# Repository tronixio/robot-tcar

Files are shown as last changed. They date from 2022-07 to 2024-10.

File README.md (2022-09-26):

# DRAFT - ROBOT - TCAR 4 Wheels.

## TCAR Features.

- 4 Wheels.
- 4 DC Motors.
- Power 2xCells 18650 Lithium Ion Rechargeable Batteries, with embedded charger.
- [4WD Motor Smart Car Chassis.](http://www.dagurobot.com/Robot-Chassis/HC021-P)

## TCAR All Schematics.

- [TODO - MCU Board PIC-16BIT.](https://github.com/tronixio/robot-tcar/blob/main/Kicad/mcu/extras/schematic.pdf)
- [DRAFT - Motors Board LP298.](https://github.com/tronixio/robot-tcar/blob/main/Kicad/motors/extras/schematic.pdf)

<!--
## TCAR Code.

- [PWM.](https://github.com/tronixio/robot-tbot/blob/main/Code/pwm/)

## TCAR MCU PIC 16Bit Top.

![TCAR MCU Top.](https://raw.githubusercontent.com/tronixio/robot-tcar/main/Kicad/mcu/extras/top.png)

## TCAR MCU PIC 16Bit Bottom.

![TCAR MCU Top.](https://raw.githubusercontent.com/tronixio/robot-tcar/main/Kicad/mcu/extras/top.png)
-->

## TCAR Motor Top.

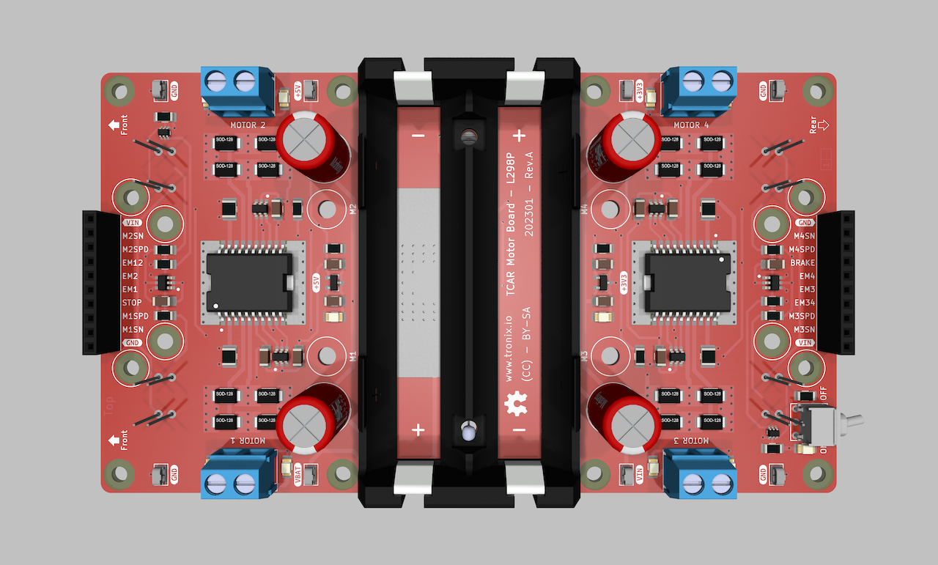
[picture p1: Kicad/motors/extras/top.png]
TCAR Motor Top.


## TCAR Motor Bottom.

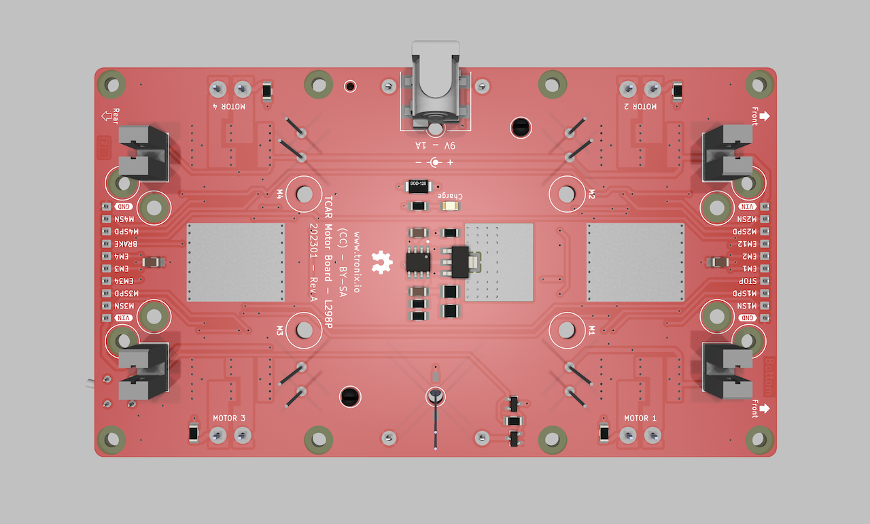
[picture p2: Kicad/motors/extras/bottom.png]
TCAR Motor Bottom.


!!! note

    - TODO : Work in progress, prototype was not good, hardware, PCB and code can be rework.
    - DRAFT : Prototype OK, last check schematic, PCB & code can be modify.

!!! example "DISCLAIMER"

    THIS CODE IS PROVIDED WITHOUT ANY WARRANTY OR GUARANTEES.
    USERS MAY USE THIS CODE FOR DEVELOPMENT AND EXAMPLE PURPOSES ONLY.
    AUTHORS ARE NOT RESPONSIBLE FOR ANY ERRORS, OMISSIONS, OR DAMAGES THAT COULD
    RESULT FROM USING THIS FIRMWARE IN WHOLE OR IN PART.

---

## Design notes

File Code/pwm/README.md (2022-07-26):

# PWM - 16-BIT Pulse-Width Modulation Module.

## Code.

- [PWM 16-BIT - RC Servo Forward & Backward.](https://github.com/tronixio/robot-tbot/blob/main/Code/pwm/pwm.s)

## Oscilloscope.

### Stop.

- MCU.RC5.PWM.6  -> Oscilloscope Probe A
- MCU.RB5.PWM.11 -> Oscilloscope Probe B

<p align="center">
PWM.6 - PWM.11
</p>

### Forward.

- MCU.RC5.PWM.6  -> Oscilloscope Probe A
- MCU.RB5.PWM.11 -> Oscilloscope Probe B

<p align="center">
PWM.6 - PWM.11
</p>

### Backward.

- MCU.RC5.PWM.6  -> Oscilloscope Probe A
- MCU.RB5.PWM.11 -> Oscilloscope Probe B

<p align="center">
PWM.6 - PWM.11
</p>

## Notes.

- TODO : Work in progress, prototype was not good, hardware, PCB and code can be rework.
- DRAFT : Prototype OK, last check schematic, PCB & code can be modify.

## DISCLAIMER.

THIS CODE IS PROVIDED WITHOUT ANY WARRANTY OR GUARANTEES.
USERS MAY USE THIS CODE FOR DEVELOPMENT AND EXAMPLE PURPOSES ONLY.
AUTHORS ARE NOT RESPONSIBLE FOR ANY ERRORS, OMISSIONS, OR DAMAGES THAT COULD
RESULT FROM USING THIS FIRMWARE IN WHOLE OR IN PART.

---

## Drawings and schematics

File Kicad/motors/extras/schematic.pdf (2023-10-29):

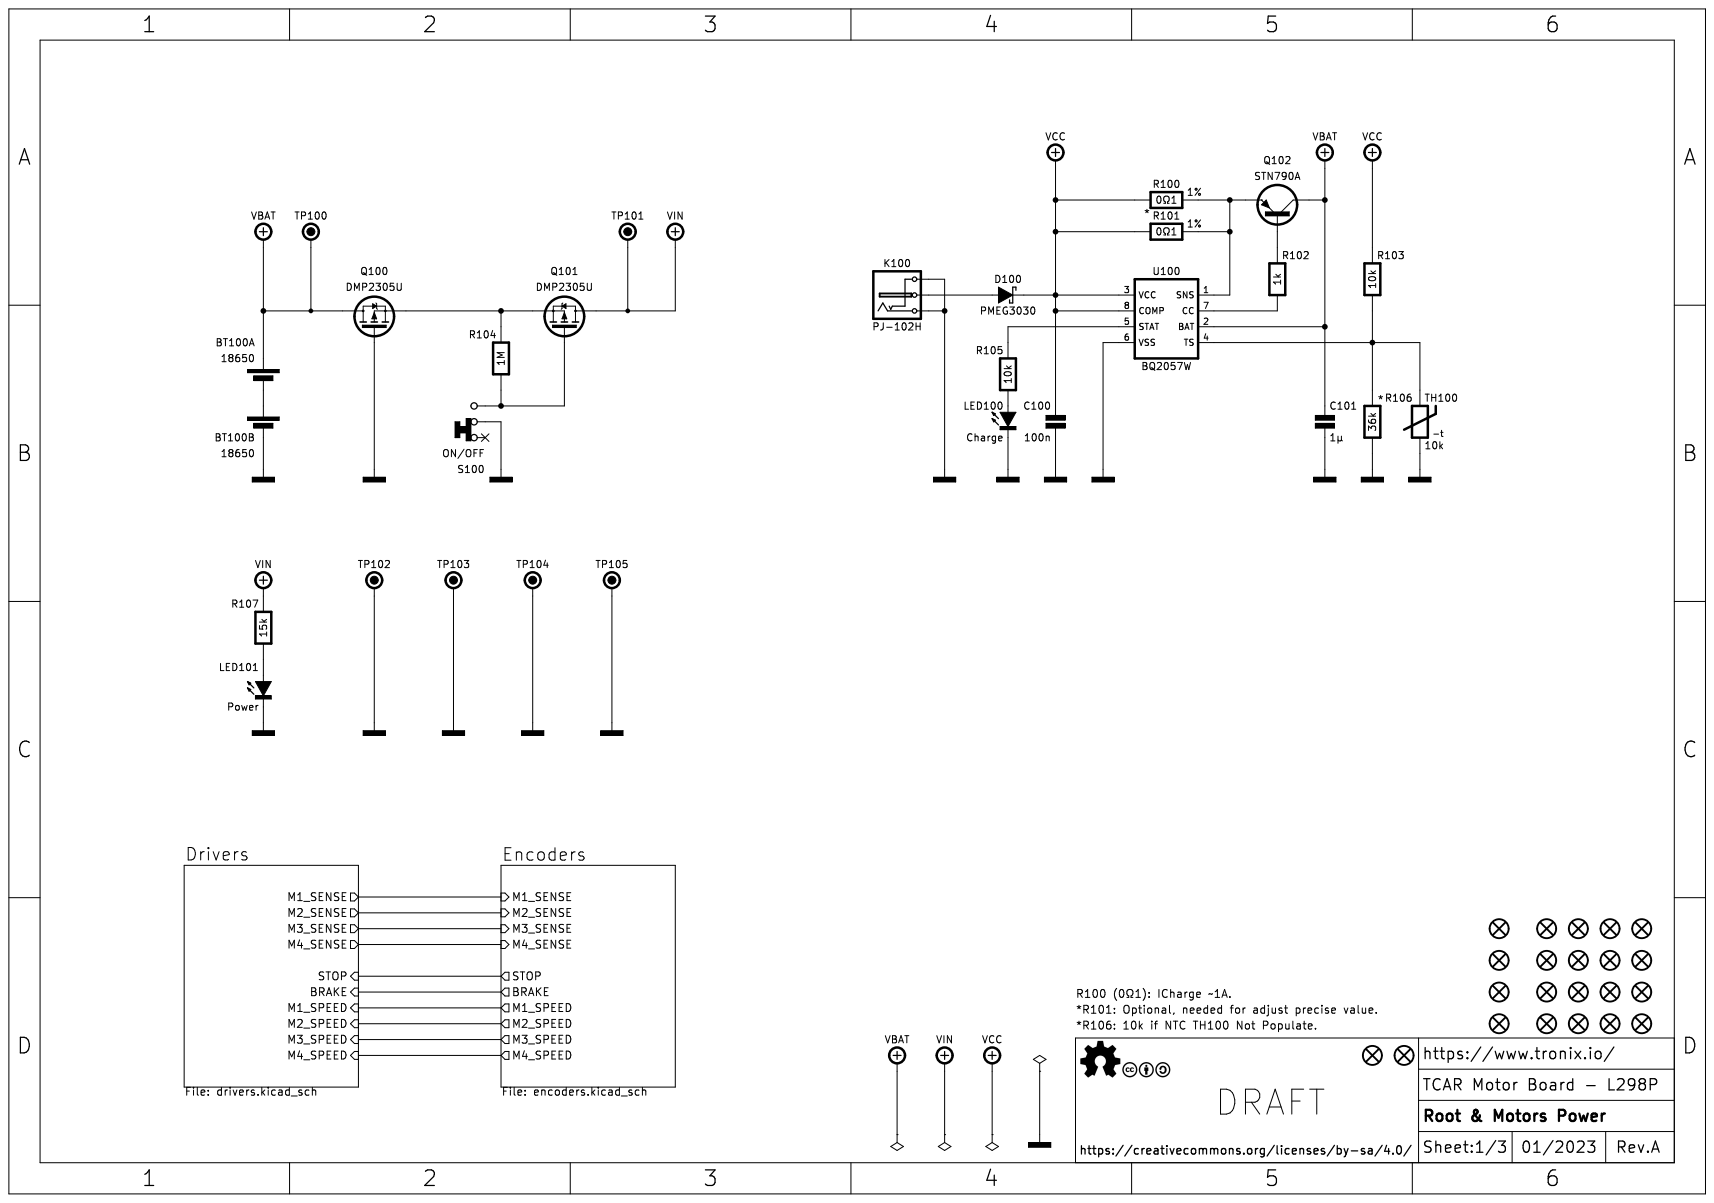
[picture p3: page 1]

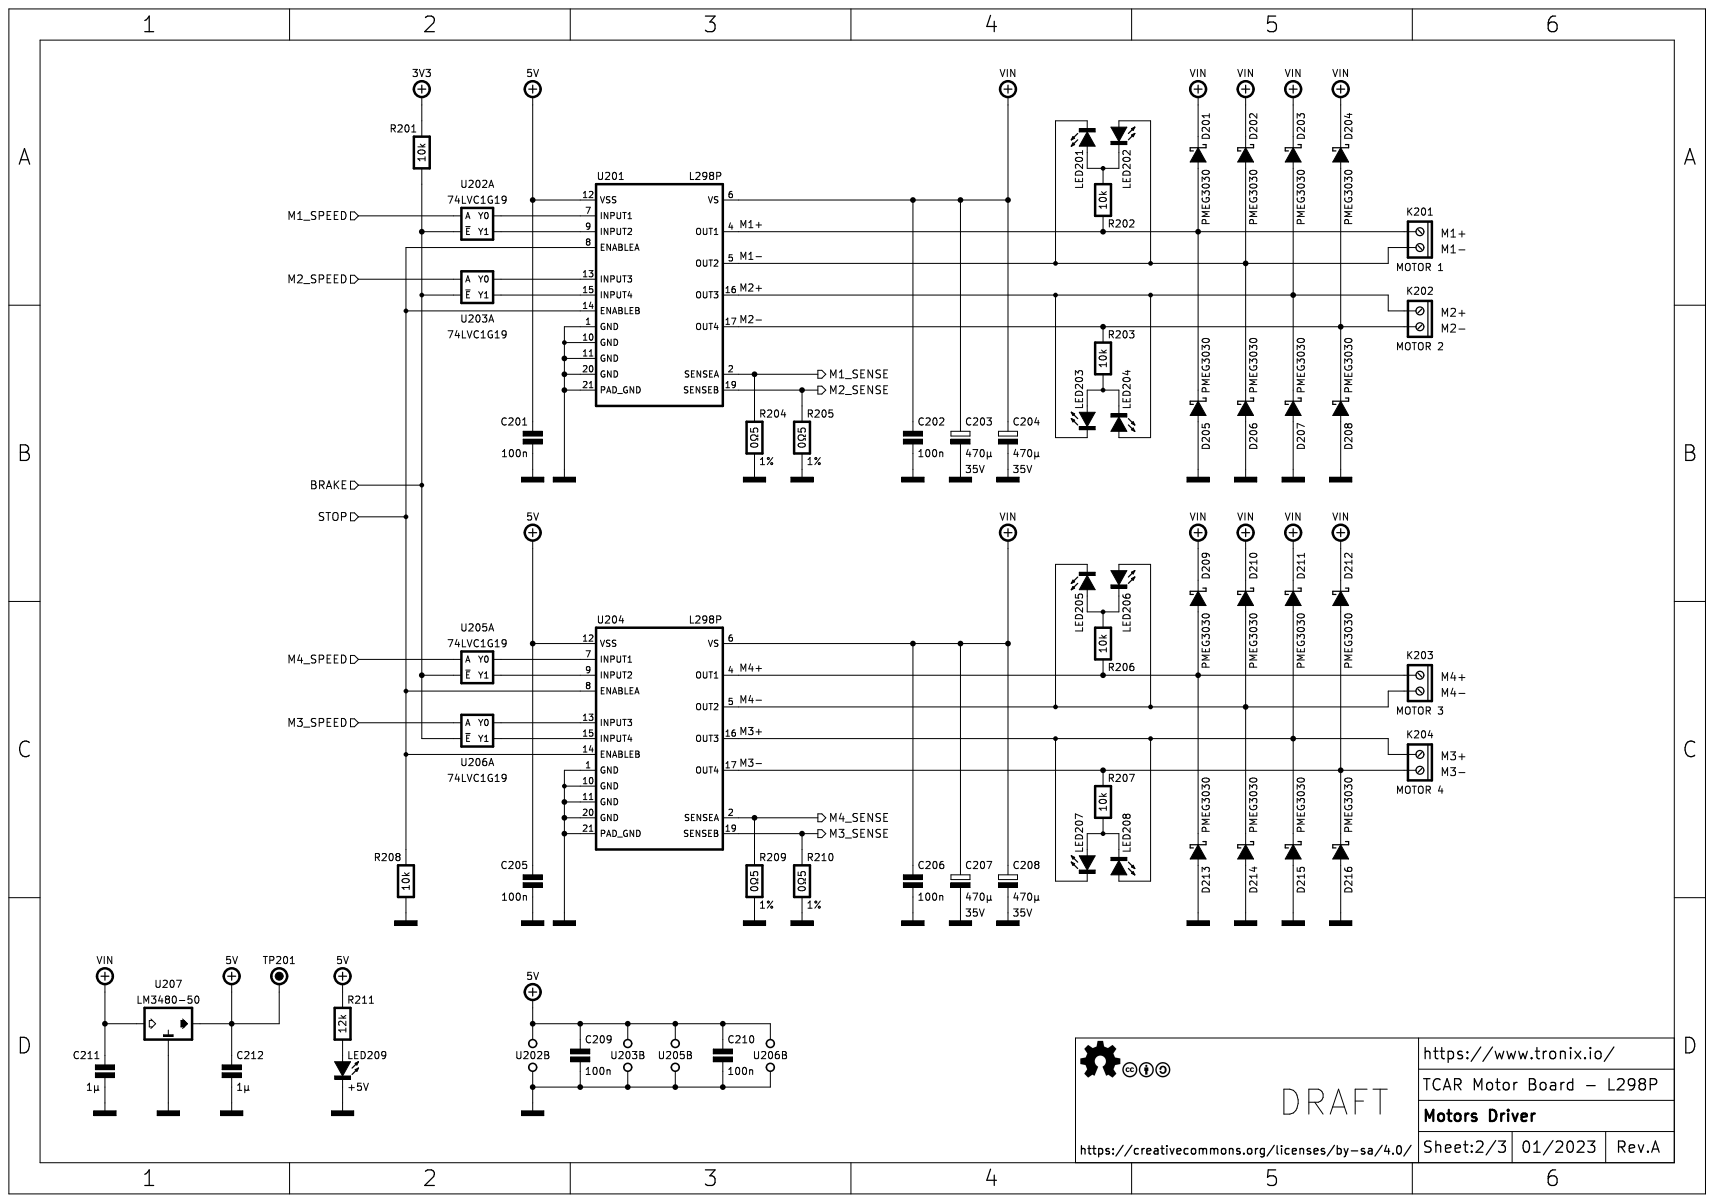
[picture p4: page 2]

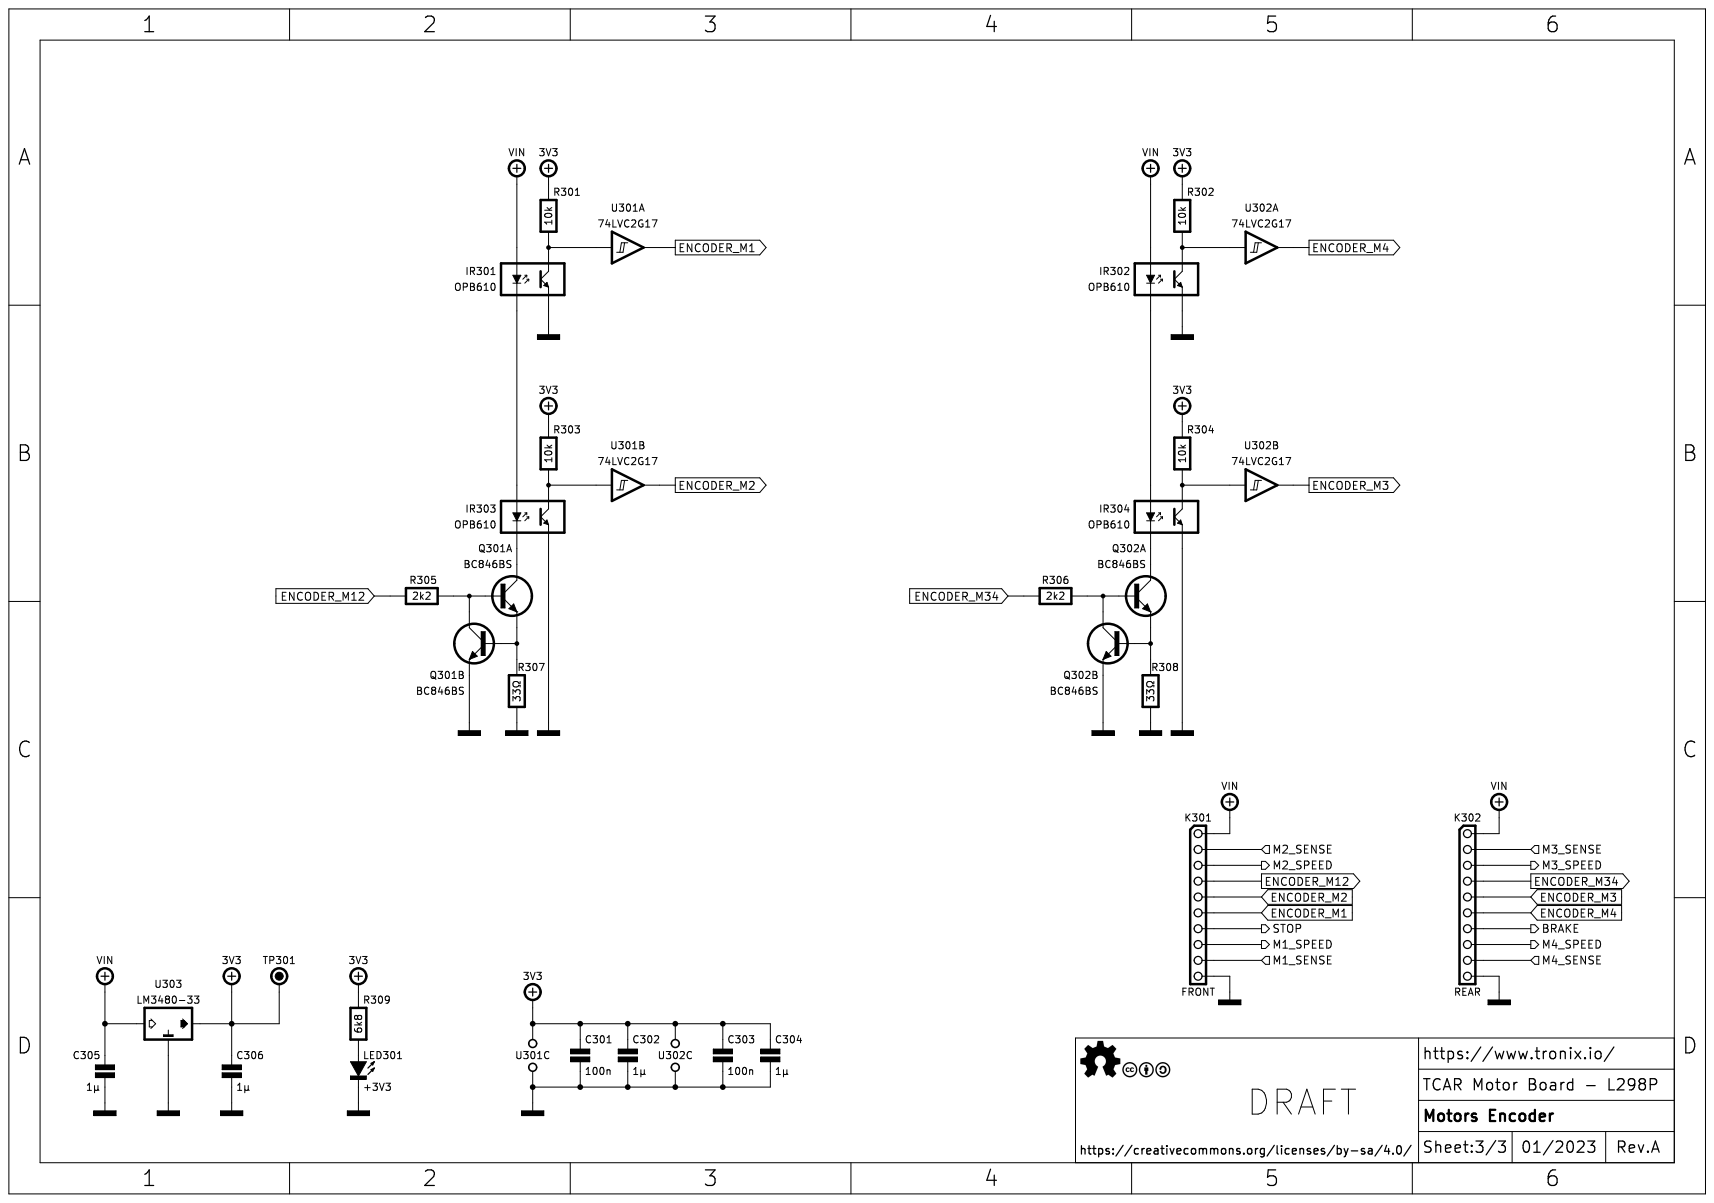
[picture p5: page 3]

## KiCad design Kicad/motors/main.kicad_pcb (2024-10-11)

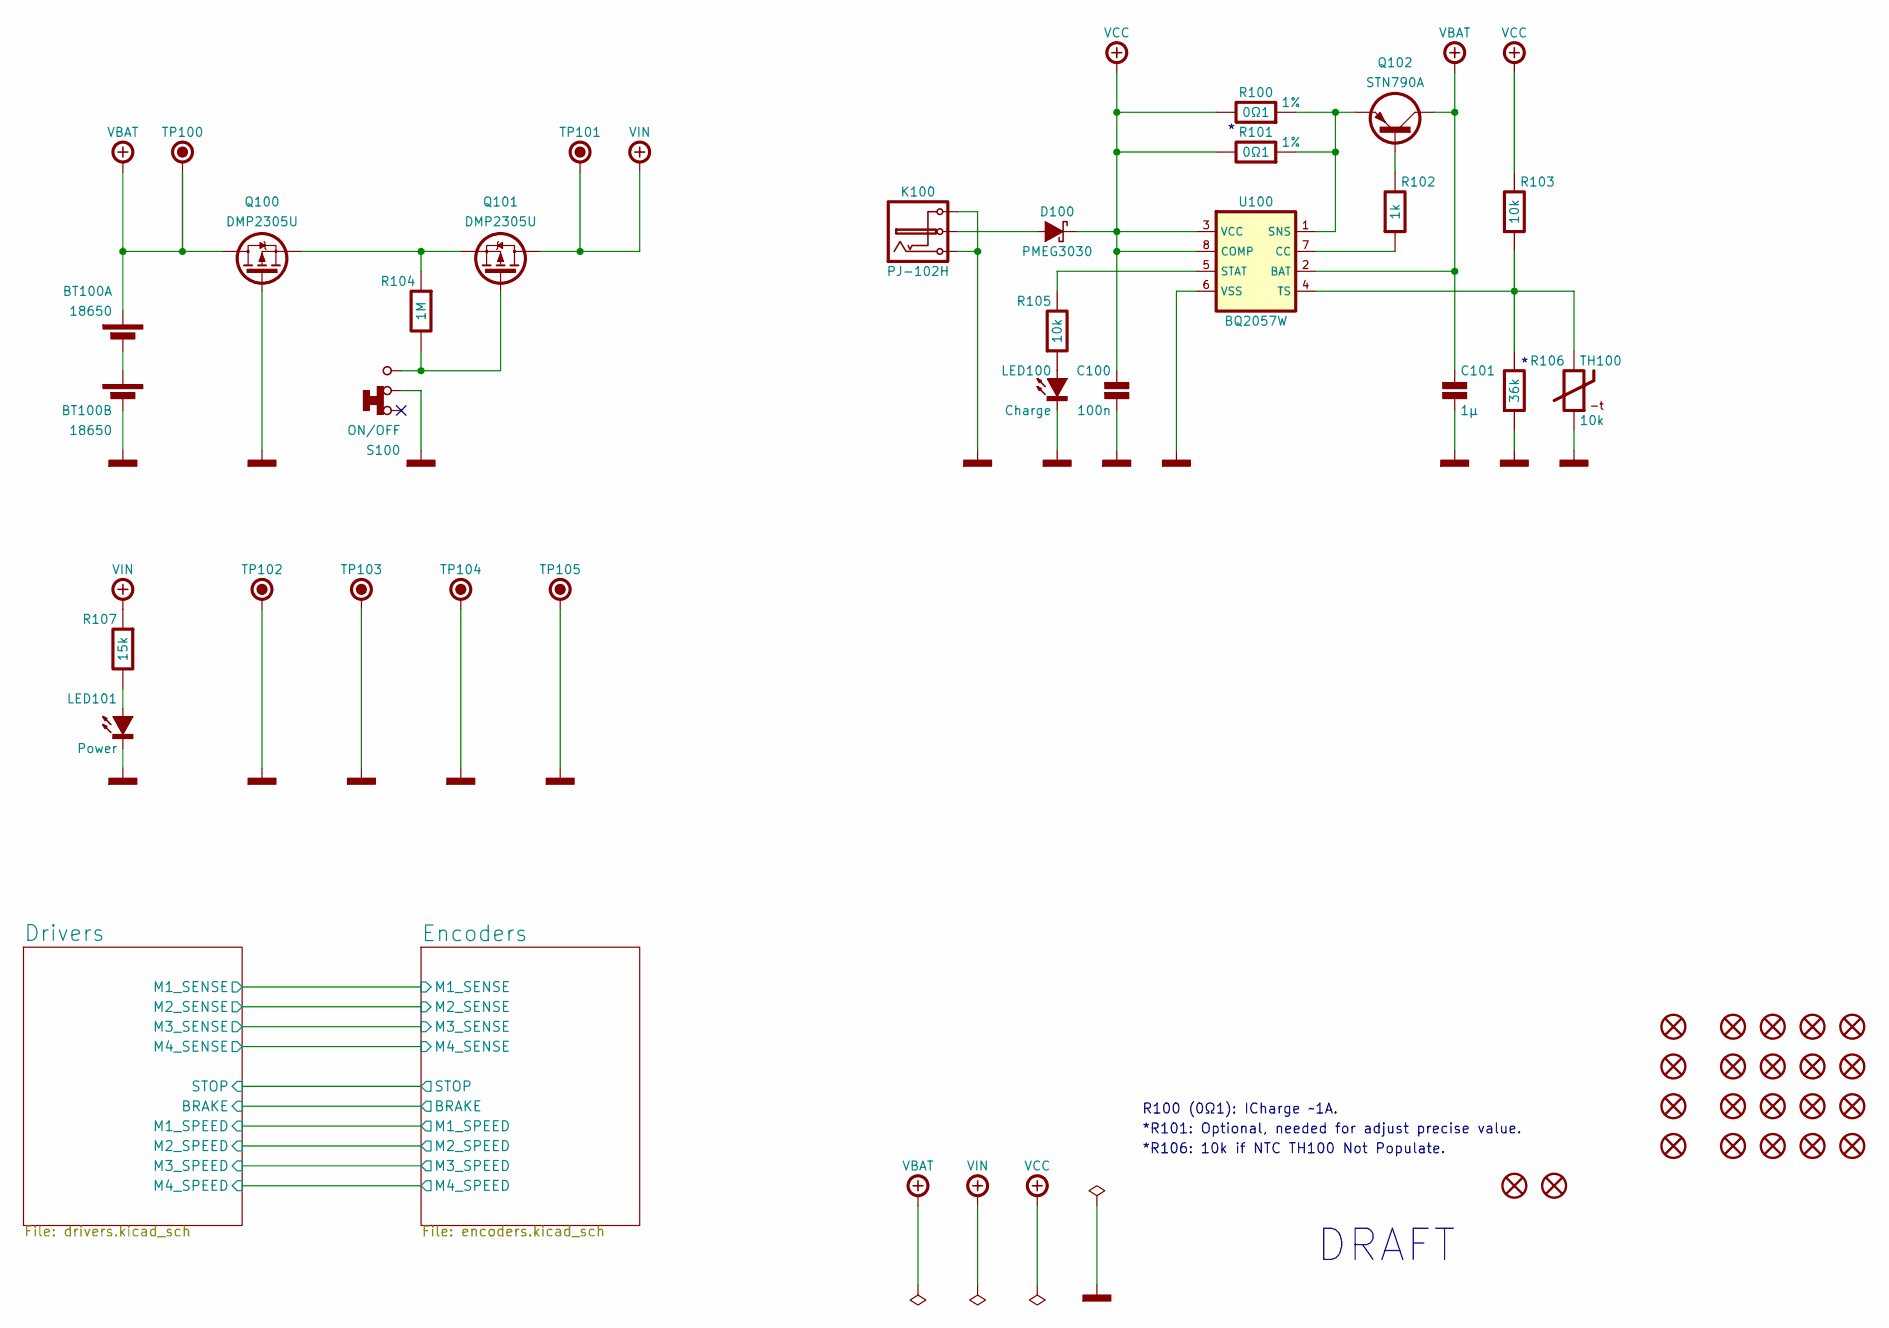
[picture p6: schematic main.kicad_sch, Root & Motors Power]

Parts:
BT100: 18650; KEYSTONE-1049; Mouser 534-1049
C100: 100n; CAPACITOR-SMD-1206; Voltage 50V; Tolerance 5%; Mouser 80-C1206C104J5R
C101: 1µ; CAPACITOR-SMD-1206; Voltage 16V; Tolerance 10%; Mouser 80-C1206C105K4R
D100: PMEG3030; SOD-128; Mouser 771-PMEG3030EP115
H101, H102, H103, H104, H105, H106, H107, H108, H109, H110, H111, H112, H113, H114, H115, H116: MOUNTING-HOLE-3MM-MASK
H117, H118, H119, H120: MOUNTING-HOLE-3.5MM
K100: PJ-102H; CUI-PJ-002AH-SMT-TR; Mouser 490-PJ-002AH-SMT-TR
LED100: Charge; LED-SMD-1206; Mouser 604-APT3216LSECKJ3RV
LED101: Power; LED-SMD-1206; Mouser 604-APT3216LSECKJ3RV
Q100, Q101: DMP2305U; SOT-23-3; Mouser 621-DMP2305U-7
Q102: STN790A; SOT-223-3; Mouser 511-STN790A
R100, R101: 0Ω1; RESISTOR-SMD-1210; Tolerance 1%; Mouser 660-SR732ETTER100F
R102: 1k; RESISTOR-SMD-1206; Tolerance 5%; Mouser 660-RK73B2BTTDD102J
R103, R105: 10k; RESISTOR-SMD-1206; Tolerance 5%; Mouser 660-RK73B2BTTDD103J
R104: 1M; RESISTOR-SMD-1206; Tolerance 5%; Mouser 660-RK73B2BTTDD105J
R106: 36k; RESISTOR-SMD-1206; Tolerance 5%; Mouser 660-RK73B2BTTDD363J
R107: 15k; RESISTOR-SMD-1206; Tolerance 5%; Mouser 660-RK73B2BTTDD153J
S100: ON/OFF; E-SWITCH-200USPXT1A1M6RE; Mouser 612-200USP1T1A1M6RE
TH100: 10k; THERMISTOR-SMD; Mouser 594-NTCLE213E3103FL
TP100, TP101, TP102, TP103, TP104, TP105: HARWIN-S1751; Mouser 855-S1751-46
U100: BQ2057W; SOIC-08; Mouser 595-BQ2057WSN
X101, X102: OSHW-5MM

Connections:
+VBAT: BT100.2 (+), C101.1, Q100.3 (D), Q102.2 (C), TP100.1, U100.2 (BAT)
+VCC: C100.1, D100.1 (C), R100.1, R101.1, R103.1, U100.3 (VCC), U100.8 (COMP)
+VIN: Q101.3 (D), R107.2, TP101.1; also elsewhere on the board
GND: BT100.3 (-), C100.2, C101.2, K100.2, K100.3, LED100.1 (C), LED101.1 (C), Q100.1 (G), R106.2, S100.2, TH100.2, TP102.1, TP103.1, TP104.1, TP105.1, U100.6 (VSS); also elsewhere on the board
unnamed: BT100.1 (-), BT100.4 (+)
unnamed: D100.2 (A), K100.1
unnamed: LED100.2 (A), R105.2
unnamed: LED101.2 (A), R107.1
unnamed: Q100.2 (S), Q101.2 (S), R104.2
unnamed: Q101.1 (G), R104.1, S100.3
unnamed: Q102.1 (B), R102.1
unnamed: Q102.3 (E), R100.2, R101.2, U100.1 (SNS)
unnamed: R102.2, U100.7 (CC)
unnamed: R105.1, U100.5 (STAT)
unnamed: R103.2, R106.1, TH100.1, U100.4 (TS)

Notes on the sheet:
DRAFT
*R101: Optional, needed for adjust precise value.
*R106: 10k if NTC TH100 Not Populate.
R100 (0Ω1): ICharge ~1A.

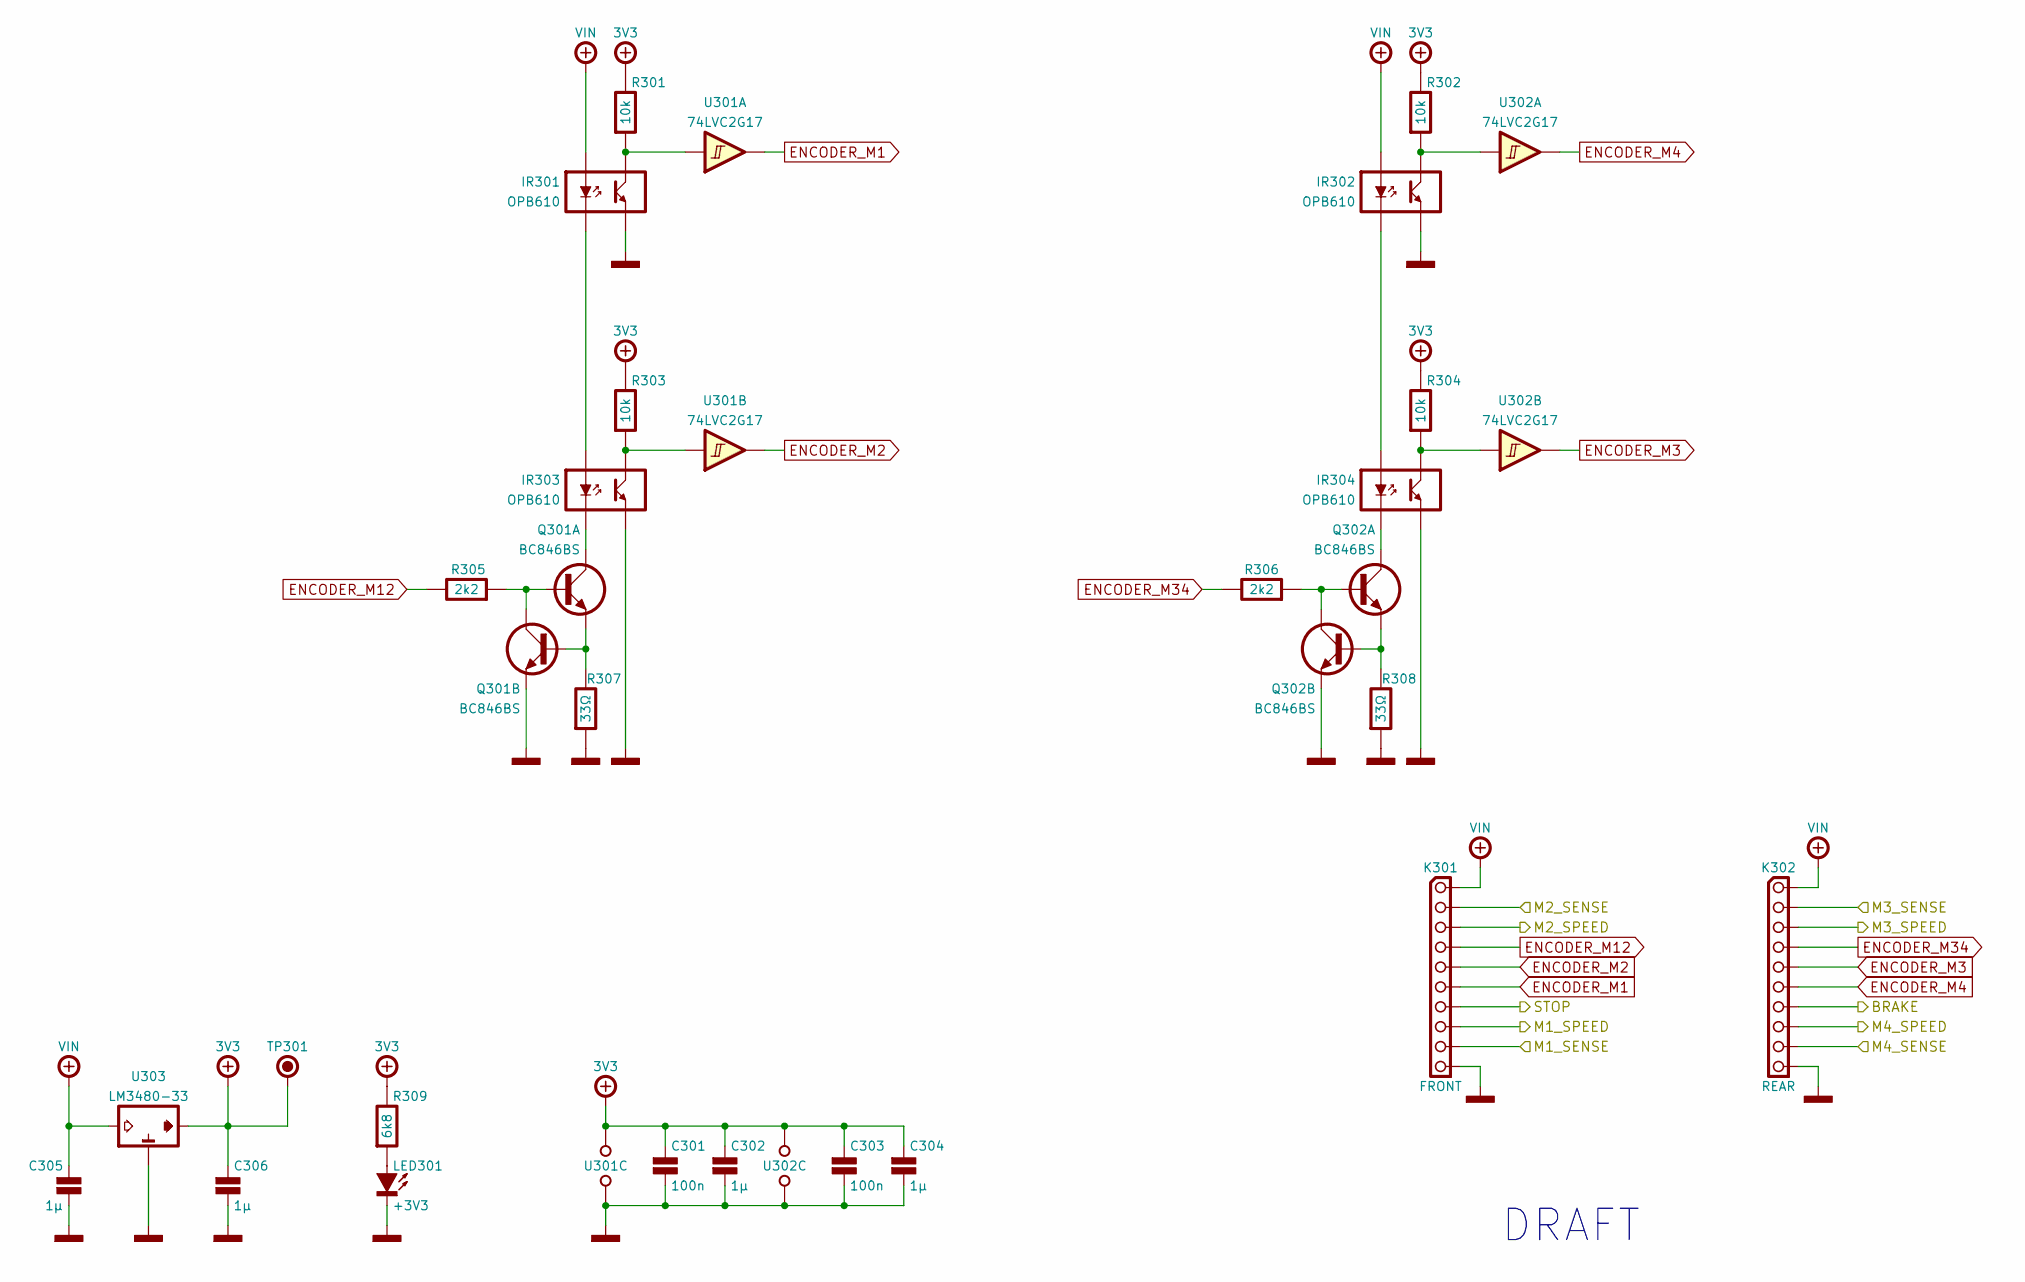
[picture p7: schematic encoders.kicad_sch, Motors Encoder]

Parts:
C301, C303: 100n; CAPACITOR-SMD-1206; Voltage 50V; Tolerance 5%; Mouser 80-C1206C104J5R
C302, C304, C305, C306: 1µ; CAPACITOR-SMD-1206; Voltage 16V; Tolerance 10%; Mouser 80-C1206C105K4R
IR301, IR302, IR303, IR304: OPB610; OPB-610; Mouser 828-OPB610
K301: FRONT; HARWIN-M20-782104x; Mouser 855-M20-782104
K302: REAR; HARWIN-M20-782104x; Mouser 855-M20-782104
LED301: +3V3; LED-SMD-1206; Mouser 604-APT3216LSECKJ3RV
Q301, Q302: BC846BS; SC-70-6; Mouser 771-BC846BS115
R301, R302, R303, R304: 10k; RESISTOR-SMD-1206; Tolerance 5%; Mouser 660-RK73B2BTTDD103J
R305, R306: 2k2; RESISTOR-SMD-1206; Tolerance 5%; Mouser 660-RK73B2BTTDD222J
R307, R308: 33Ω; RESISTOR-SMD-1206; Tolerance 5%; Mouser 660-RK73B2BTTDD330J
R309: 6k8; RESISTOR-SMD-1206; Tolerance 5%; Mouser 660-RK73B2BTTD682J
TP301: HARWIN-S1751; Mouser 855-S1751-46
U301, U302: 74LVC2G17; SOT-23-6; Mouser 595-SN74LVC2G17D
U303: LM3480-33; SOT-23-3; Mouser 926-LM3480IM33.3NOPB

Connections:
+3V3: C301.1, C302.1, C303.1, C304.1, C306.1, R301.1, R302.1, R303.1, R304.1, R309.1, TP301.1, U301.5 (VCC), U302.5 (VCC), U303.1 (VOUT); also elsewhere on the board
+VIN: C305.1, IR301.1 (ANODE), IR302.1 (ANODE), K301.1, K302.1, U303.2 (VIN); also elsewhere on the board
/Drivers/BRAKE: K302.7; also elsewhere on the board
/Drivers/M1_SENSE: K301.9; also elsewhere on the board
/Drivers/M1_SPEED: K301.8; also elsewhere on the board
/Drivers/M2_SENSE: K301.2; also elsewhere on the board
/Drivers/M2_SPEED: K301.3; also elsewhere on the board
/Drivers/M3_SENSE: K302.2; also elsewhere on the board
/Drivers/M3_SPEED: K302.3; also elsewhere on the board
/Drivers/M4_SENSE: K302.9; also elsewhere on the board
/Drivers/M4_SPEED: K302.8; also elsewhere on the board
/Drivers/STOP: K301.7; also elsewhere on the board
ENCODER_M1: K301.6, U301.6 (1Y)
ENCODER_M2: K301.5, U301.4 (2Y)
ENCODER_M3: K302.5, U302.4 (2Y)
ENCODER_M4: K302.6, U302.6 (1Y)
ENCODER_M12: K301.4, R305.1
ENCODER_M34: K302.4, R306.1
GND: C301.2, C302.2, C303.2, C304.2, C305.2, C306.2, IR301.4 (EMITTER), IR302.4 (EMITTER), IR303.4 (EMITTER), IR304.4 (EMITTER), K301.10, K302.10, LED301.1 (C), Q301.4 (E), Q302.4 (E), R307.2, R308.2, U301.2 (GND), U302.2 (GND), U303.3 (GND); also elsewhere on the board
unnamed: IR301.2 (CATHODE), IR303.1 (ANODE)
unnamed: IR301.3 (COLLECTOR), R301.2, U301.1 (1A)
unnamed: IR302.2 (CATHODE), IR304.1 (ANODE)
unnamed: IR302.3 (COLLECTOR), R302.2, U302.1 (1A)
unnamed: IR303.2 (CATHODE), Q301.6 (C)
unnamed: IR303.3 (COLLECTOR), R303.2, U301.3 (2A)
unnamed: IR304.2 (CATHODE), Q302.6 (C)
unnamed: IR304.3 (COLLECTOR), R304.2, U302.3 (2A)
unnamed: LED301.2 (A), R309.2
unnamed: Q301.2 (B), Q301.3 (C), R305.2
unnamed: Q301.1 (E), Q301.5 (B), R307.1
unnamed: Q302.2 (B), Q302.3 (C), R306.2
unnamed: Q302.1 (E), Q302.5 (B), R308.1

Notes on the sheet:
DRAFT

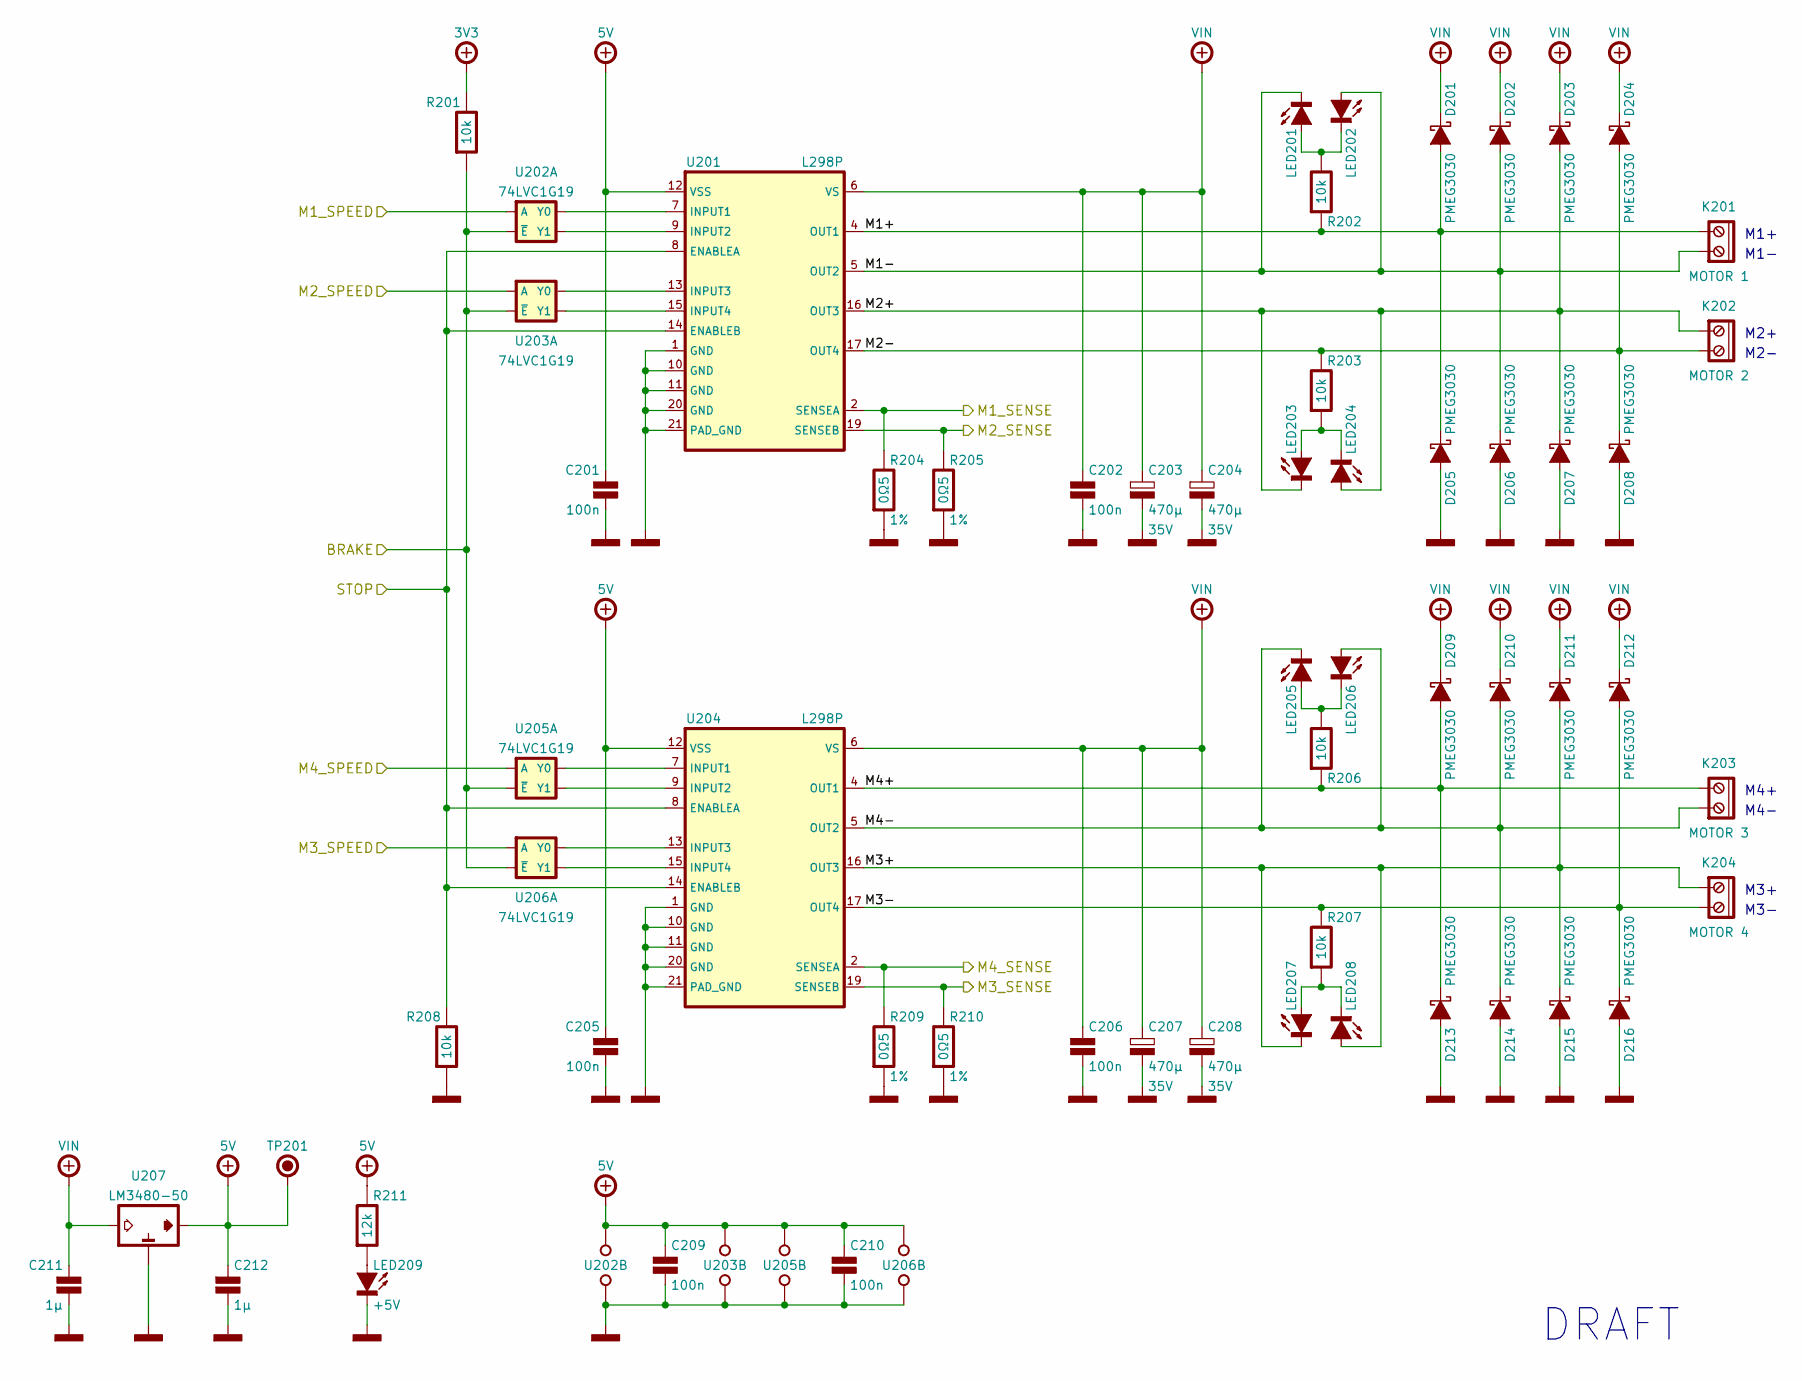
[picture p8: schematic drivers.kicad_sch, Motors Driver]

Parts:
C201, C202, C205, C206, C209, C210: 100n; CAPACITOR-SMD-1206; Voltage 50V; Tolerance 5%; Mouser 80-C1206C104J5R
C203, C204, C207, C208: 470µ; CAPACITOR-ELECTROLYTIC-RADIAL-100-160-050-WURTH; Tolerance 20%; Voltage 35V; Mouser 710-860010575013
C211, C212: 1µ; CAPACITOR-SMD-1206; Voltage 16V; Tolerance 10%; Mouser 80-C1206C105K4R
D201, D202, D203, D204, D205, D206, D207, D208, D209, D210, D211, D212, D213, D214, D215, D216: PMEG3030; SOD-128; Mouser 771-PMEG3030EP115
K201: MOTOR 1; CUI-TB006-508-02BE; Mouser 490-TB006-508-02BE
K202: MOTOR 2; CUI-TB006-508-02BE; Mouser 490-TB006-508-02BE
K203: MOTOR 3; CUI-TB006-508-02BE; Mouser 490-TB006-508-02BE
K204: MOTOR 4; CUI-TB006-508-02BE; Mouser 490-TB006-508-02BE
LED201, LED202, LED203, LED204, LED205, LED206, LED207, LED208: RED; LED-SMD-1206; Mouser 604-APT3216LSECKJ3RV
LED209: +5V; LED-SMD-1206; Mouser 604-APT3216LSECKJ3RV
R201, R202, R203, R206, R207, R208: 10k; RESISTOR-SMD-1206; Tolerance 5%; Mouser 660-RK73B2BTTDD103J
R204, R205, R209, R210: 0Ω5; RESISTOR-SMD-1210; Tolerance 1%; Mouser 660-SR732ETTDR499F
R211: 12k; RESISTOR-SMD-1206; Tolerance 5%; Mouser 660-RK73B2BTTD123J
TP201: HARWIN-S1751; Mouser 855-S1751-46
U201, U204: L298P; SOPOWER-20; Mouser 511-L298P-TR
U202, U203, U205, U206: 74LVC1G19; SOT-23-6; Mouser 595-SN74LVC1G19D
U207: LM3480-50; SOT-23-3; Mouser 926-LM3480IM35.0NOPB

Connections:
+3V3: R201.1; also elsewhere on the board
+5V: C201.1, C205.1, C209.1, C210.1, C212.1, R211.1, TP201.1, U201.12 (VSS), U202.5 (VCC), U203.5 (VCC), U204.12 (VSS), U205.5 (VCC), U206.5 (VCC), U207.1 (VOUT)
+VIN: C202.1, C203.1, C204.1, C206.1, C207.1, C208.1, C211.1, D201.1 (C), D202.1 (C), D203.1 (C), D204.1 (C), D209.1 (C), D210.1 (C), D211.1 (C), D212.1 (C), U201.6 (VS), U204.6 (VS), U207.2 (VIN); also elsewhere on the board
/Drivers/BRAKE: R201.2, U202.3 (~E), U203.3 (~E), U205.3 (~E), U206.3 (~E); also elsewhere on the board
/Drivers/M1+: D201.2 (A), D205.1 (C), K201.2, R202.2, U201.4 (OUT1)
/Drivers/M1-: D202.2 (A), D206.1 (C), K201.1, LED201.1 (C), LED202.2 (A), U201.5 (OUT2)
/Drivers/M1_SENSE: R204.1, U201.2 (SENSEA); also elsewhere on the board
/Drivers/M1_SPEED: U202.1 (A); also elsewhere on the board
/Drivers/M2+: D203.2 (A), D207.1 (C), K202.1, LED203.1 (C), LED204.2 (A), U201.16 (OUT3)
/Drivers/M2-: D204.2 (A), D208.1 (C), K202.2, R203.1, U201.17 (OUT4)
/Drivers/M2_SENSE: R205.1, U201.19 (SENSEB); also elsewhere on the board
/Drivers/M2_SPEED: U203.1 (A); also elsewhere on the board
/Drivers/M3+: D211.2 (A), D215.1 (C), K204.1, LED207.1 (C), LED208.2 (A), U204.16 (OUT3)
/Drivers/M3-: D212.2 (A), D216.1 (C), K204.2, R207.1, U204.17 (OUT4)
/Drivers/M3_SENSE: R210.1, U204.19 (SENSEB); also elsewhere on the board
/Drivers/M3_SPEED: U206.1 (A); also elsewhere on the board
/Drivers/M4+: D209.2 (A), D213.1 (C), K203.2, R206.2, U204.4 (OUT1)
/Drivers/M4-: D210.2 (A), D214.1 (C), K203.1, LED205.1 (C), LED206.2 (A), U204.5 (OUT2)
/Drivers/M4_SENSE: R209.1, U204.2 (SENSEA); also elsewhere on the board
/Drivers/M4_SPEED: U205.1 (A); also elsewhere on the board
/Drivers/STOP: R208.1, U201.8 (ENABLEA), U201.14 (ENABLEB), U204.8 (ENABLEA), U204.14 (ENABLEB); also elsewhere on the board
GND: C201.2, C202.2, C203.2, C204.2, C205.2, C206.2, C207.2, C208.2, C209.2, C210.2, C211.2, C212.2, D205.2 (A), D206.2 (A), D207.2 (A), D208.2 (A), D213.2 (A), D214.2 (A), D215.2 (A), D216.2 (A), LED209.1 (C), R204.2, R205.2, R208.2, R209.2, R210.2, U201.1 (GND), U201.10 (GND), U201.11 (GND), U201.20 (GND), U201.21 (PAD_GND), U202.2 (GND), U203.2 (GND), U204.1 (GND), U204.10 (GND), U204.11 (GND), U204.20 (GND), U204.21 (PAD_GND), U205.2 (GND), U206.2 (GND), U207.3 (GND); also elsewhere on the board
unnamed: LED201.2 (A), LED202.1 (C), R202.1
unnamed: LED203.2 (A), LED204.1 (C), R203.2
unnamed: LED205.2 (A), LED206.1 (C), R206.1
unnamed: LED207.2 (A), LED208.1 (C), R207.2
unnamed: LED209.2 (A), R211.2
unnamed: U201.7 (INPUT1), U202.6 (Y0)
unnamed: U201.9 (INPUT2), U202.4 (Y1)
unnamed: U201.13 (INPUT3), U203.6 (Y0)
unnamed: U201.15 (INPUT4), U203.4 (Y1)
unnamed: U204.7 (INPUT1), U205.6 (Y0)
unnamed: U204.9 (INPUT2), U205.4 (Y1)
unnamed: U204.13 (INPUT3), U206.6 (Y0)
unnamed: U204.15 (INPUT4), U206.4 (Y1)

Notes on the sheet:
M3-
M1+
M2+
M4-
M2-
DRAFT
M3+
M4+
M1-

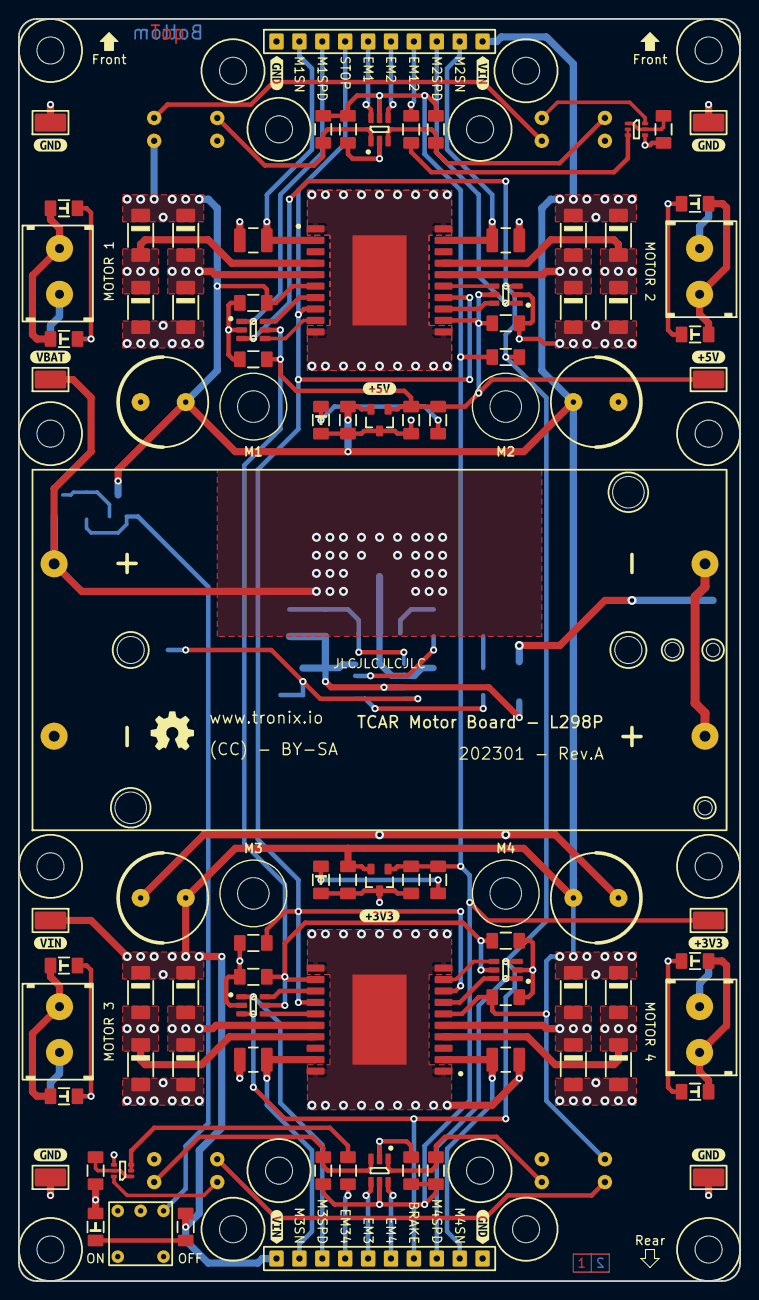
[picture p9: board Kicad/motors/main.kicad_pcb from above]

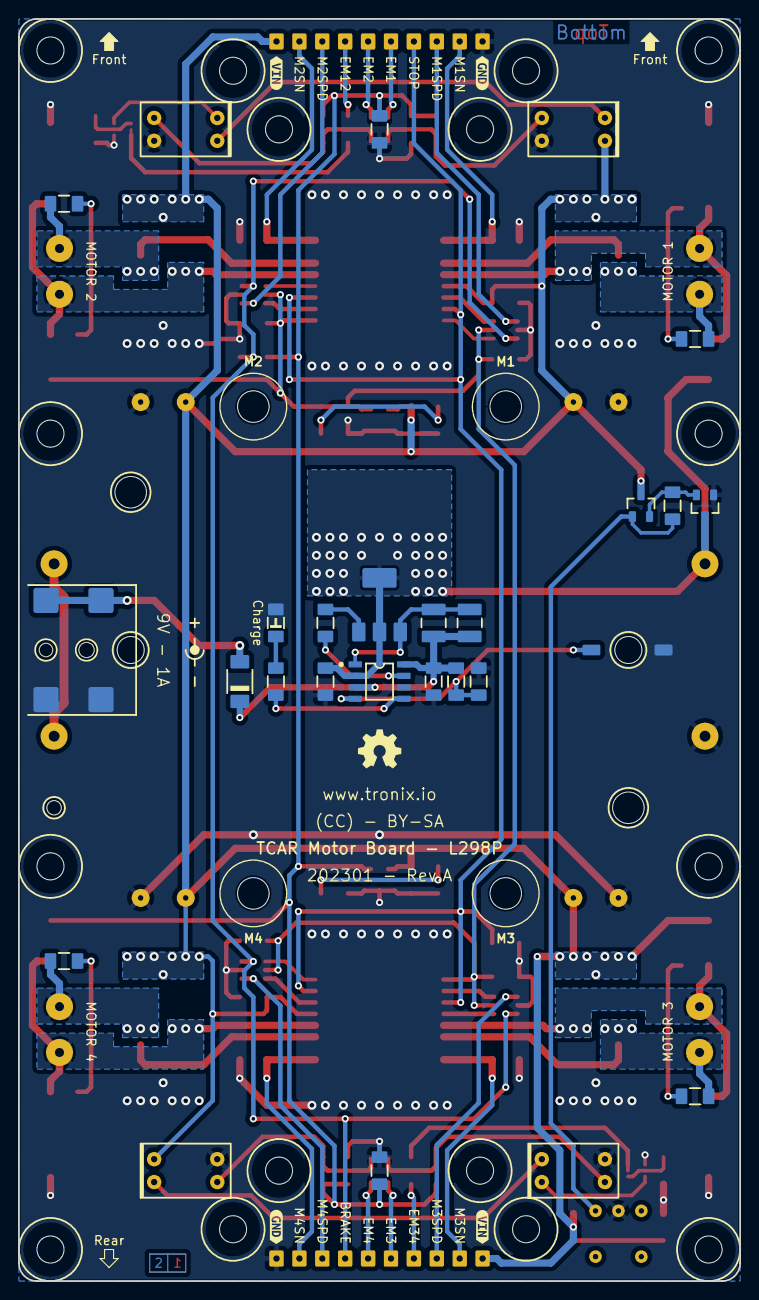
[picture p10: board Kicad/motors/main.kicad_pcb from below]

Board: 2 copper layers, 80.0 x 140.0 mm, 155 parts (32 on the bottom side), 67 nets.

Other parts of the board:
kibuzzard-64482FBD: G***; kibuzzard-64482FBD
kibuzzard-64482FE5: G***; kibuzzard-64482FE5
kibuzzard-628974BE, kibuzzard-628974BE#2: G***; kibuzzard-628974BE
kibuzzard-628977DB: G***; kibuzzard-628977DB
kibuzzard-628977F0: G***; kibuzzard-628977F0
kibuzzard-6289753B, kibuzzard-6289753B#2: G***; kibuzzard-6289753B
kibuzzard-6289769F, kibuzzard-6289769F#2: G***; kibuzzard-6289769F
kibuzzard-6289784D: G***; kibuzzard-6289784D
kibuzzard-6289786A: G***; kibuzzard-6289786A
kibuzzard-62897416, kibuzzard-62897416#2: G***; kibuzzard-62897416
kibuzzard-62897505, kibuzzard-62897505#2: G***; kibuzzard-62897505
kibuzzard-62897802: G***; kibuzzard-62897802
kibuzzard-62897881: G***; kibuzzard-62897881

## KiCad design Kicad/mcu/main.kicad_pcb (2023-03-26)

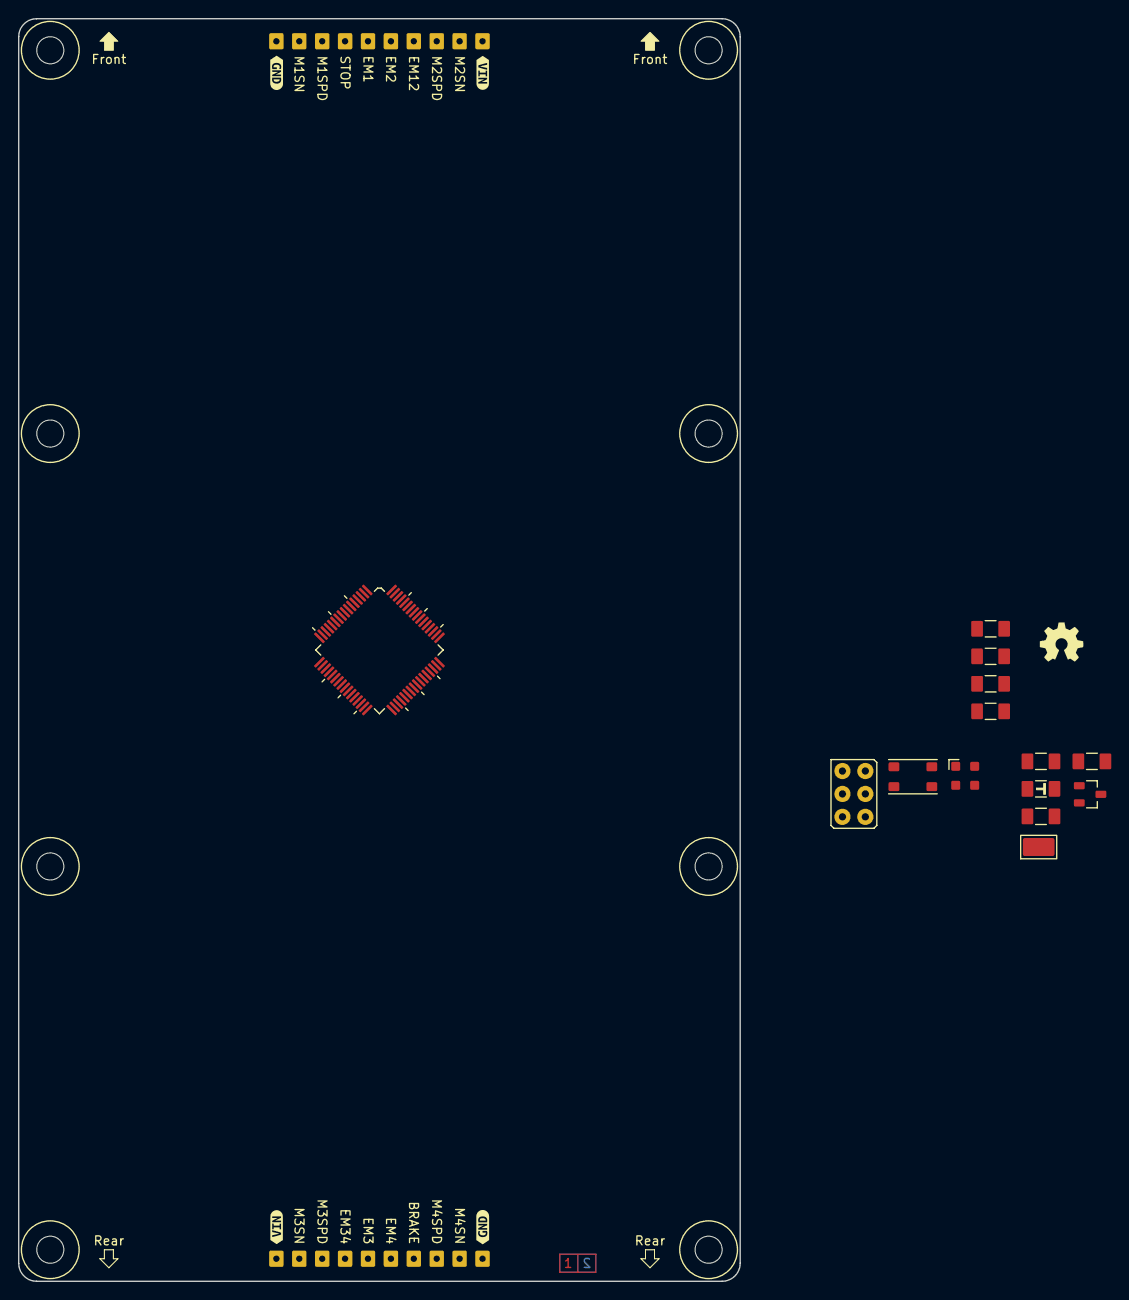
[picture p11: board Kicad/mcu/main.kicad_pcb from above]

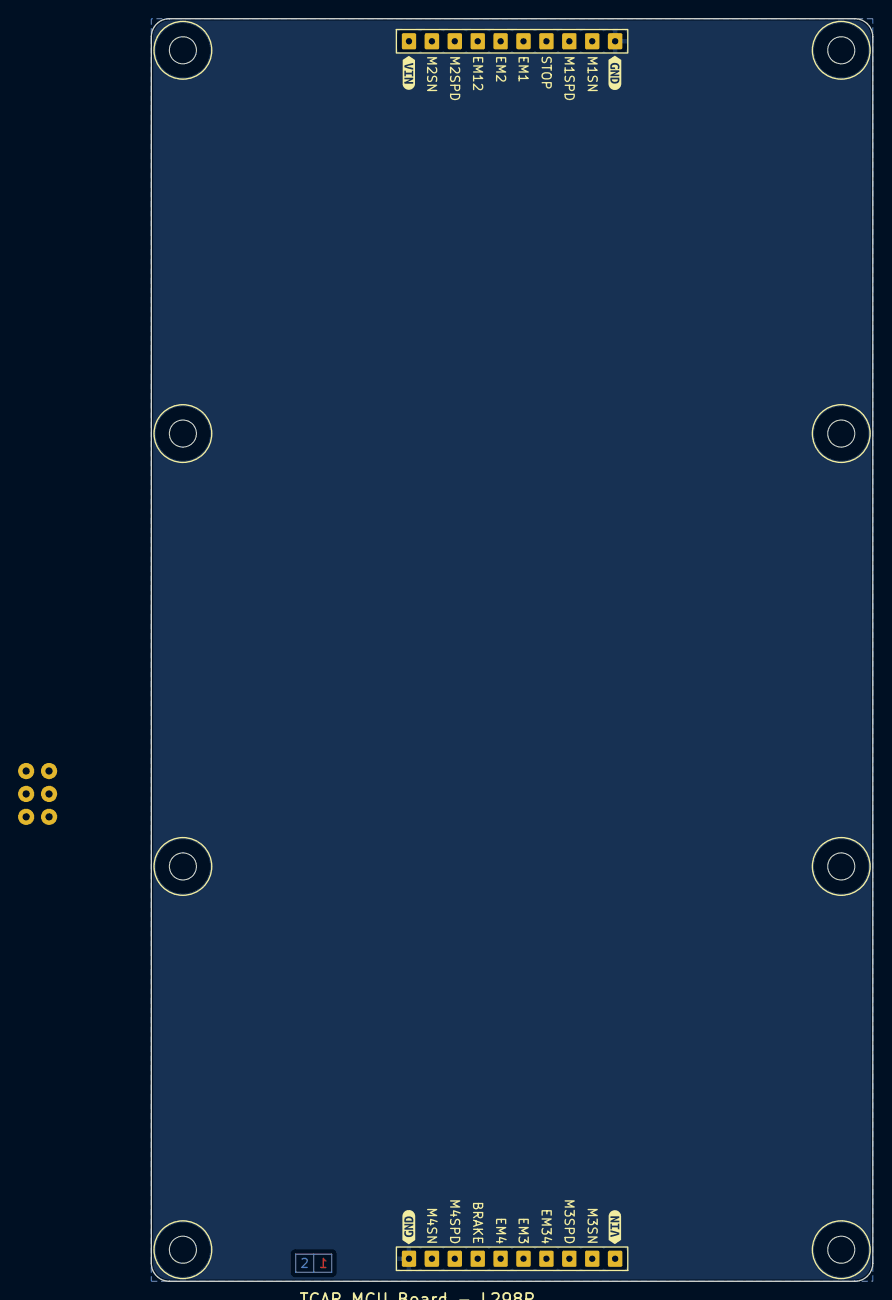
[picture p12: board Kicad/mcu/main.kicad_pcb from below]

Board: 2 copper layers, 80.0 x 140.0 mm, 34 parts (7 on the bottom side), 5 nets, no tracks yet.

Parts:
C101, C102: 1µ; CAPACITOR-SMD-1206
C201, C202: 100n; CAPACITOR-SMD-1206
H101, H102, H103, H104, H105, H106, H107, H108: MOUNTING-HOLE-MASK-3MM; MOUNTING-HOLE-3MM-MASK
IC101: LM3480-33; SOT-23-3
IC201: MICROCHIP-PIC24FJ64GA106-TQFP; TQFP-64
K201: ICSP; HARWIN-M20-998034x
K301: Front; HARWIN-M20-782104x
K302: Rear; HARWIN-M20-782104x
LED101: Power; LED-SMD-1206
MEMS201: MICROCHIP-DSC1001C-245760-CDFN; CDFN-3225
R101: 6K8; RESISTOR-SMD-1206
R201: 10K; RESISTOR-SMD-1206
R202: 1K; RESISTOR-SMD-1206
S201: Reset; ALPS-SKRPAC
TP101: HARWIN-S1751
X101, X102: SYMBOL-MISC; OSHW-5MM
kibuzzard-64205CDF, kibuzzard-64205CDF#2, kibuzzard-64205CDF#3, kibuzzard-64205CDF#4: G***; kibuzzard-64205CDF
kibuzzard-628974BE, kibuzzard-628974BE#2, kibuzzard-628974BE#3, kibuzzard-628974BE#4: G***; kibuzzard-628974BE

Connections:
+3V3: C102.1, C202.1, K201.2 (VDD), R101.1, TP101.1
GND: C101.2, C102.2, C201.2, C202.2, IC101.3 (GND), K301.1, K302.1, LED101.1 (C), S201.1, S201.2
unnamed: C201.1, R201.1, R202.2, S201.3, S201.4
unnamed: LED101.2 (A), R101.2
VIN: C101.1, K301.10, K302.10

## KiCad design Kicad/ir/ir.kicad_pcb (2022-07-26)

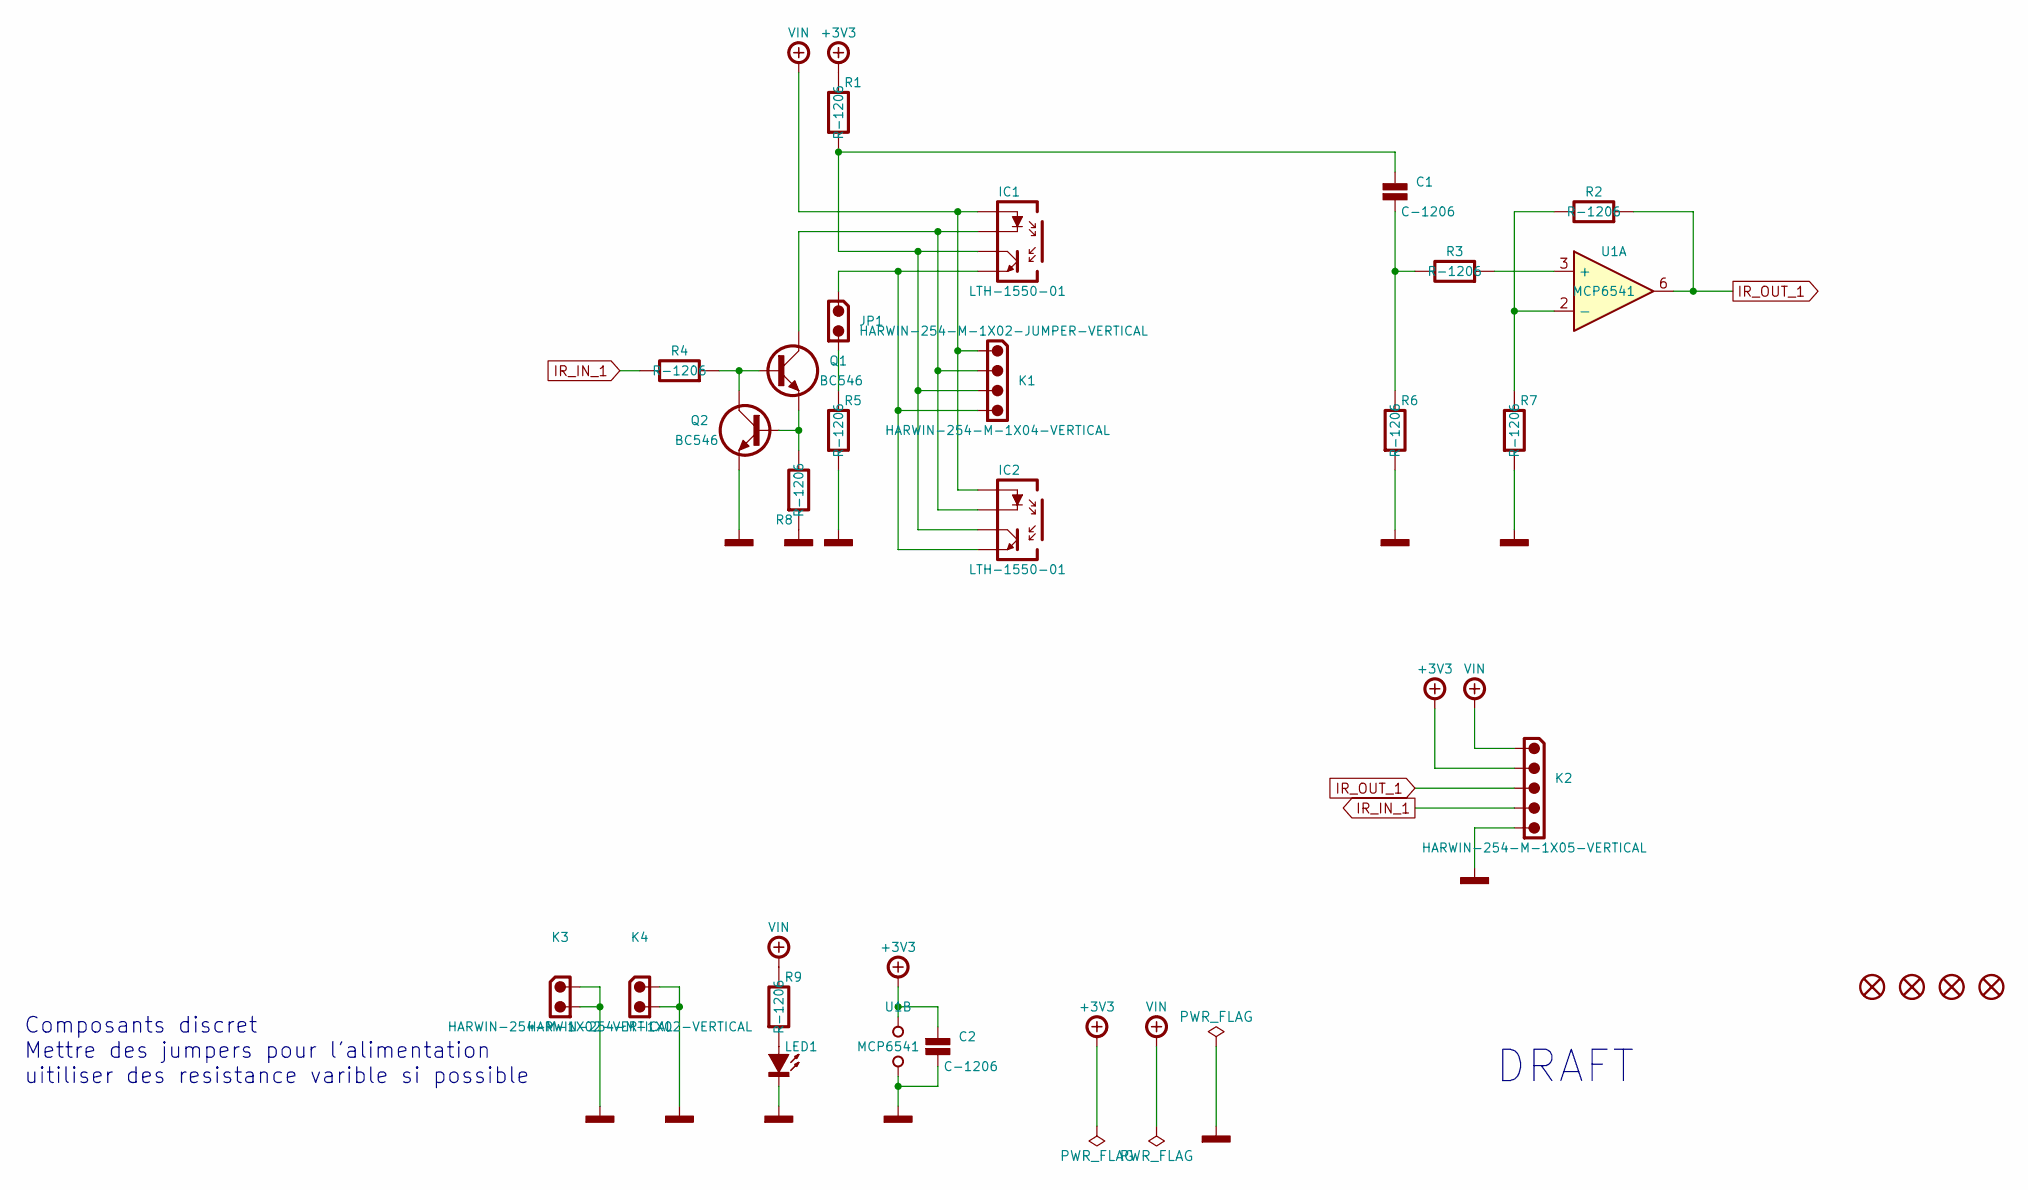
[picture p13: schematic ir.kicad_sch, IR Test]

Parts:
C1, C2: C-1206
H1, H2, H3, H4: MOUNTING-HOLE-MASK-3MM; M3-MASK
IC1, IC2: Mouser 859-LTH-1550-01
JP1: HARWIN-254-M-1X02-JUMPER-VERTICAL; HARWIN-M20-999024x; Mouser 855-M20-999024
K1: HARWIN-254-M-1X04-VERTICAL; HARWIN-M20-999044x; Mouser 855-M20-999044
K2: HARWIN-254-M-1X05-VERTICAL; HARWIN-M20-999054x; Mouser 855-M20-999054
K3, K4: HARWIN-254-M-1X02-VERTICAL; HARWIN-M20-999024x; Mouser 55-M20-9990245
LED1: Mouser 604-APT3216LSECKJ3RV
Q1: Mouser 512-BC546ABU
Q2: ONSEMI-BC546-TO92; TO-92-INLINE; Mouser 512-BC546ABU
R1, R2, R3, R4, R5, R6, R7, R8, R9: R-1206
U1: Mouser 579-MCP6541-I/P

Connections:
+3V3: C2.1, K2.2, R1.1, U1.7 (VDD)
GND: C2.2, K2.5, K3.1, K3.2, K4.1, K4.2, LED1.1 (K), Q2.3 (E), R5.2, R6.2, R7.2, R8.2, U1.4 (GND)
IR_IN_1: K2.4, R4.1
IR_OUT_1: K2.3, R2.2, U1.6
unnamed: C1.1, IC1.3 (COLLECTOR), IC2.3 (COLLECTOR), K1.3, R1.2
unnamed: C1.2, R3.1, R6.1
unnamed: IC1.2 (CATHODE), IC2.2 (CATHODE), K1.2, Q1.1 (C)
unnamed: IC1.4 (EMITTER), IC2.4 (EMITTER), JP1.1, K1.4
unnamed: JP1.2, R5.1
unnamed: LED1.2 (A), R9.2
unnamed: Q1.2 (B), Q2.1 (C), R4.2
unnamed: Q1.3 (E), Q2.2 (B), R8.1
unnamed: R2.1, R7.1, U1.2 (-)
unnamed: R3.2, U1.3 (+)
VIN: IC1.1 (ANODE), IC2.1 (ANODE), K1.1, K2.1, R9.1

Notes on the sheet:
DRAFT
Composants discret Mettre des jumpers pour l'alimentation uitiliser des resistance varible si possible

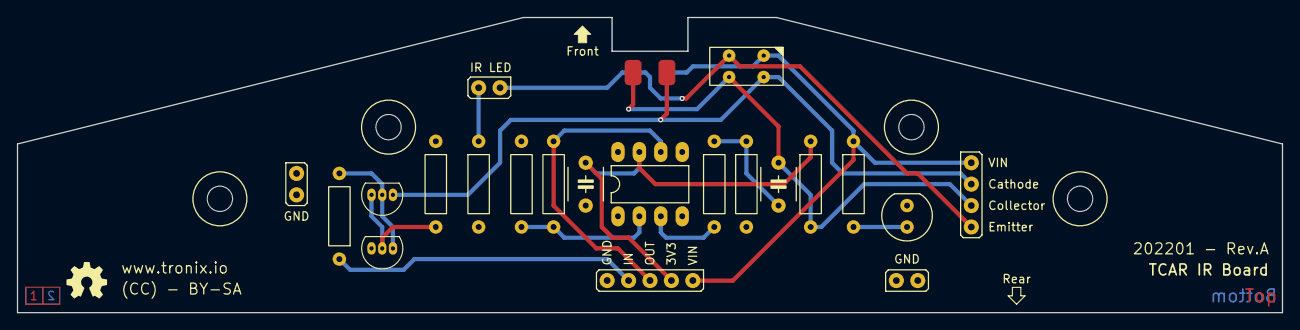
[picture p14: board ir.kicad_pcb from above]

Board: 2 copper layers, 150.0 x 35.0 mm, 26 parts (1 on the bottom side), 15 nets.

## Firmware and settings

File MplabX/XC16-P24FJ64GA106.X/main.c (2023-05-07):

// Configuration Registers.
#pragma config WPFP = WPFP511, WPDIS = WPDIS, WPCFG = WPCFGDIS
#pragma config WPEND = WPENDMEM, POSCMOD = EC, IOL1WAY = ON, OSCIOFNC = OFF
#pragma config FCKSM = CSDCMD, FNOSC = PRI, IESO = OFF, WDTPS = PS32768
#pragma config FWPSA = PR128, WINDIS = OFF, FWDTEN = OFF, ICS = PGx2
#pragma config GWRP = OFF, GCP = OFF, JTAGEN = OFF

// MCU Frequency.
#define FOSC    (24576000UL)
#define FCY     (FOSC/2)

#include <xc.h>
#include <libpic30.h>
#include <p24FJ64GA106.h>
// PIC24FJ64GA106 - Compile with XC16(v2.10).
// PIC24FJ64GA106 - @24.576MHz External Oscillator.
// v0.1 - xx/2023.

// TCAR - Rev.A.

// TODO: EUSART Tx
// TODO: EUSART Rx
// TODO: Read Battery
// TODO: Motor function VBAT
// TODO: Motor Ramp
// TODO: Motor Encoder

// Pinout.
// MCU.RB1 -> LED1.
// MCU.RB2 -> LED2.
// MCU.RF3 -> LED3.
// MCU.RF2 -> LED4.
// MCU.RB5 <- SWTICH1.
// MCU.RB4 <- SWTICH2.
// MCU.RF5 <- SWTICH3.
// MCU.RF4 <- SWTICH4.

// Definitions.
// IR Encoder Motor.
#define ENCODER_M12_DISABLE        LATDbits.LATD6 = 0b0
#define ENCODER_M12_ENABLE         LATDbits.LATD6 = 0b1
#define ENCODER_M34_DISABLE        LATBbits.LATB10 = 0b0
#define ENCODER_M34_ENABLE         LATBbits.LATB10 = 0b1
// LED.
#define LED1_OFF                   LATBbits.LATB1 = 0b0
#define LED1_ON                    LATBbits.LATB1 = 0b1
#define LED2_OFF                   LATBbits.LATB2 = 0b0
#define LED2_ON                    LATBbits.LATB2 = 0b1
#define LED3_OFF                   LATFbits.LATF3 = 0b0
#define LED3_ON                    LATFbits.LATF3 = 0b1
#define LED4_OFF                   LATFbits.LATF2 = 0b0
#define LED4_ON                    LATFbits.LATF2 = 0b1
// Motor.
#define MOTOR_PWM_FREQUENCY         ((FCY/15000)-1)
#define MOTOR_PWM_DUTY_CYCLE_STOP   410
#define MOTOR_PWM_FRONT_LEFT        OC1R
#define MOTOR_PWM_FRONT_RIGHT       OC2R
#define MOTOR_PWM_REAR_LEFT         OC3R
#define MOTOR_PWM_REAR_RIGHT        OC4R
#define MOTOR_STOP_ENGAGE           LATDbits.LATD7 = 0b0
#define MOTOR_STOP_RELEASE          LATDbits.LATD7 = 0b1
#define MOTOR_BRAKE_ENGAGE          LATBbits.LATB13 = 0b1
#define MOTOR_BRAKE_RELEASE         LATBbits.LATB13 = 0b0
// Switch.
#define SWITCH1                     PORTBbits.RB5
#define SWITCH2                     PORTBbits.RB4
#define SWITCH3                     PORTFbits.RF5
#define SWITCH4                     PORTFbits.RF4

// Main.
int main(void)
{
    // MCU Initialization.
    // Oscillator Settings.
    CLKDIVbits.DOZE = 0b00;
    CLKDIVbits.DOZEN = 0b0;
    // Ports Initialization.
    // Analog Inputs Settings.
    AD1PCFGL = 0b1111111111111110;
    AD1PCFGH = 0b0000000000000011;
    // PORTB Settings.
    TRISB = 0b1000000100110001;
    PORTB = 0b0000000000000000;
    LATB = 0b0000000000000000;
    ODCB = 0b0000000000000000;
    // PORTC Settings.
    TRISC = 0b0000000000000000;
    PORTC = 0b0000000000000000;
    LATC = 0b0000000000000000;
    ODCC = 0b0000000000000000;
    // PORTD Settings.
    TRISD = 0b0000000000000110;
    PORTD = 0b0000000000000000;
    LATD = 0b0000000000000000;
    ODCD = 0b0000000000000000;
    // PORTE Settings.
    TRISE = 0b0000000000000000;
    PORTE = 0b0000000000000000;
    LATE = 0b0000000000000000;
    ODCE = 0b0000000000000000;
    // PORTF Settings.
    TRISF = 0b0000000000110000;
    PORTF = 0b0000000000000000;
    LATF = 0b0000000000000000;
    ODCF = 0b0000000000000000;
    // PORTG Settings.
    TRISG = 0b0000000000000000;
    PORTG = 0b0000000000000000;
    LATG = 0b0000000000000000;
    ODCG = 0b0000000000000000;
    // PPS Initialization.
    __builtin_write_OSCCONL(OSCCON & 0xBF);
    // PPS Inputs Settings.
    RPINR7bits.IC1R = 0x17;		// RD2  - RP23 - IC1R.
    RPINR7bits.IC2R = 0x18;		// RD1  - RP24 - IC2R.
    RPINR8bits.IC3R = 0x8;		// RB8  - RP8  - IC3R.
    RPINR8bits.IC4R = 0x1D;		// RB15 - RP29 - IC4R.
    // PPS Outputs Settings.
    RPOR10bits.RP20R = 0x12;    // RD5  - RP20 - OC1.
    RPOR12bits.RP25R = 0x13;    // RD4  - RP25 - OC2.
    RPOR4bits.RP9R = 0x14;      // RB9  - RP9  - OC3.
    RPOR7bits.RP14R = 0x15;     // RB14 - RP14 - OC4.
    __builtin_write_OSCCONL(OSCCON | 0x40);

    // InputCapture1 Settings.
	IC1CON1bits.ICSIDL = 0b1;
	IC1CON1bits.ICTSEL = 0b111;
	IC1CON1bits.ICI = 0b00;
	IC1CON1bits.ICM = 0b011;
	IC1CON2bits.IC32 = 0b0;
	IC1CON2bits.ICTRIG = 0b0;
	IC1CON2bits.SYNCSEL = 0b00000;

    // InputCapture2 Settings.
	IC2CON1bits.ICSIDL = 0b1;
	IC2CON1bits.ICTSEL = 0b111;
	IC2CON1bits.ICI = 0b00;
	IC2CON1bits.ICM = 0b011;
	IC2CON2bits.IC32 = 0b0;
	IC2CON2bits.ICTRIG = 0b0;
	IC2CON2bits.SYNCSEL = 0b00000;

    // InputCapture3 Settings.
	IC3CON1bits.ICSIDL = 0b1;
	IC3CON1bits.ICTSEL = 0b111;
	IC3CON1bits.ICI = 0b00;
	IC3CON1bits.ICM = 0b011;
	IC3CON2bits.IC32 = 0b0;
	IC3CON2bits.ICTRIG = 0b0;
	IC3CON2bits.SYNCSEL = 0b00000;

    // InputCapture4 Settings.
	IC4CON1bits.ICSIDL = 0b1;
	IC4CON1bits.ICTSEL = 0b111;
	IC4CON1bits.ICI = 0b00;
	IC4CON1bits.ICM = 0b011;
	IC4CON2bits.IC32 = 0b0;
	IC4CON2bits.ICTRIG = 0b0;
	IC4CON2bits.SYNCSEL = 0b00000;

    // OutputCompare1 Settings.
    OC1CON1bits.OCSIDL = 0b1;
    OC1CON1bits.OCTSEL = 0b111;
    OC1CON1bits.ENFLT0 = 0b0;
    OC1CON1bits.TRIGMODE = 0b0;
    OC1CON1bits.OCM = 0b110;
    OC1CON2bits.FLTMD = 0b0;
    OC1CON2bits.FLTOUT = 0b0;
    OC1CON2bits.FLTTRIEN = 0b0;
    OC1CON2bits.OCINV = 0b0;
    OC1CON2bits.OC32 = 0b0;
    OC1CON2bits.OCTRIG = 0b0;
    OC1CON2bits.OCTRIS = 0b0;
    OC1CON2bits.SYNCSEL = 0b11111;
    OC1RS = MOTOR_PWM_FREQUENCY;
    OC1R = MOTOR_PWM_DUTY_CYCLE_STOP;

    // OutputCompare2 Settings.
    OC2CON1bits.OCSIDL = 0b1;
    OC2CON1bits.OCTSEL = 0b111;
    OC2CON1bits.ENFLT0 = 0b0;
    OC2CON1bits.TRIGMODE = 0b0;
    OC2CON1bits.OCM = 0b110;
    OC2CON2bits.FLTMD = 0b0;
    OC2CON2bits.FLTOUT = 0b0;
    OC2CON2bits.FLTTRIEN = 0b0;
    OC2CON2bits.OCINV = 0b0;
    OC2CON2bits.OC32 = 0b0;
    OC2CON2bits.OCTRIG = 0b0;
    OC2CON2bits.OCTRIS = 0b0;
    OC2CON2bits.SYNCSEL = 0b11111;
    OC2RS = MOTOR_PWM_FREQUENCY;
    OC2R = MOTOR_PWM_DUTY_CYCLE_STOP;

    // OutputCompare3 Settings.
    OC3CON1bits.OCSIDL = 0b1;
    OC3CON1bits.OCTSEL = 0b111;
    OC3CON1bits.ENFLT0 = 0b0;
    OC3CON1bits.TRIGMODE = 0b0;
    OC3CON1bits.OCM = 0b110;
    OC3CON2bits.FLTMD = 0b0;
    OC3CON2bits.FLTOUT = 0b0;
    OC3CON2bits.FLTTRIEN = 0b0;
    OC3CON2bits.OCINV = 0b0;
    OC3CON2bits.OC32 = 0b0;
    OC3CON2bits.OCTRIG = 0b0;
    OC3CON2bits.OCTRIS = 0b0;
    OC3CON2bits.SYNCSEL = 0b11111;
    OC3RS = MOTOR_PWM_FREQUENCY;
    OC3R = MOTOR_PWM_DUTY_CYCLE_STOP;

    // OutputCompare4 Settings.
    OC4CON1bits.OCSIDL = 0b1;
    OC4CON1bits.OCTSEL = 0b111;
    OC4CON1bits.ENFLT0 = 0b0;
    OC4CON1bits.TRIGMODE = 0b0;
    OC4CON1bits.OCM = 0b110;
    OC4CON2bits.FLTMD = 0b0;
    OC4CON2bits.FLTOUT = 0b0;
    OC4CON2bits.FLTTRIEN = 0b0;
    OC4CON2bits.OCINV = 0b0;
    OC4CON2bits.OC32 = 0b0;
    OC4CON2bits.OCTRIG = 0b0;
    OC4CON2bits.OCTRIS = 0b0;
    OC4CON2bits.SYNCSEL = 0b11111;
    OC4RS = MOTOR_PWM_FREQUENCY;
    OC4R = MOTOR_PWM_DUTY_CYCLE_STOP;

    // Motors Stop & Brakes Release.
    MOTOR_STOP_ENGAGE;
    MOTOR_BRAKE_RELEASE;

    // Encoders Enable.
    ENCODER_M12_ENABLE;
    ENCODER_M34_ENABLE;

    while(1){
        if(!SWITCH1){
            __delay_us(5);
            MOTOR_STOP_RELEASE;
            MOTOR_PWM_FRONT_LEFT = 20;
            LED1_ON;
        }else{
            LED1_OFF;
            MOTOR_PWM_FRONT_LEFT = 410;
        }
        if(!SWITCH2){
            __delay_us(5);
            MOTOR_STOP_RELEASE;
            MOTOR_PWM_REAR_LEFT = 20;
            LED2_ON;
        }else{
            LED2_OFF;
            MOTOR_PWM_REAR_LEFT = 410;
        }
        if(!SWITCH3){
            __delay_us(5);
            MOTOR_STOP_RELEASE;
            MOTOR_PWM_FRONT_RIGHT = 20;
            LED3_ON;
        }else{
            LED3_OFF;
            MOTOR_PWM_FRONT_RIGHT = 410;
        }
        if(!SWITCH4){
            __delay_us(5);
            MOTOR_STOP_RELEASE;
            MOTOR_PWM_REAR_RIGHT = 20;
            LED4_ON;
        }else{
            LED4_OFF;
            MOTOR_PWM_REAR_RIGHT = 410;
        }
    }
    return(0);
}

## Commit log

2022-01-23 Update Motor
    [charger.kicad_sch, driver.kicad_sch, encoder.kicad_sch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]
2022-01-23 Update Motors
    [charger.kicad_sch, driver.kicad_sch, encoder.kicad_sch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]
2022-03-24 Update MCU
    [driver.kicad_sch, hid.kicad_sch, mcu.kicad_sch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]
2022-03-24 Create IR
    [ir.kicad_pcb, ir.kicad_sch]
